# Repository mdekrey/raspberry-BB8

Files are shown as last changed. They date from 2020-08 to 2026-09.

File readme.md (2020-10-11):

# Raspberry-BB8

One developer's adventure into building a BB-8 replica, with help from his wife and friends.

## Equipment

I'm using:

* Raspberry Pi 3 model B

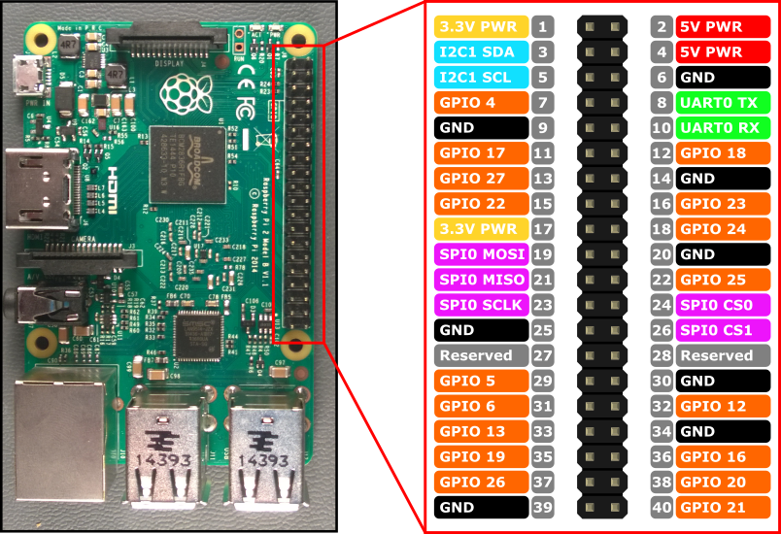
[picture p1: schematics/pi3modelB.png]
GPIO out for Raspberry Pi
    

* OSEPP Motor and Servo Shield v1.0

    OSEPP Motor and Servo Shield v1.0 Schematic

## Warnings and Pitfalls

- The Raspberry Pi 3 model B has a power management issue running the onboard wifi and bluetooth at the same time. Disable wifi if you're using the bluetooth controller, or use external dongles for either. When using wifi, the bluetooth controllers would intermittently not connect, etc.
- The OSEPP Motor and Servo Shield v1.0 Schematic had M3 and M4 reversed from what was printed on my board, and only really came with schematics for the underlying chips. See [my Programmer's Guide for the OSEPP Motor and Servo Shield](./programmers-guide-to-osepp-motor-shield.md).

## Building

1. Package the BB8 project in this repository using `dotnet`.

        dotnet publish -c Release -p:PublishSingleFile=false -p:PublishTrimmed=true -r linux-arm

    This is also saved in `publish.ps1`. With .NET 5 RC1, I found I needed turn off Single File publishing. It worked fine with .NET 5 Preview 7, however.

2. Copy the files from `\src\BB8\bin\Release\net5.0\linux-arm\publish` via to the Pi.

    * I [set up an SSH server on my Windows 10 machine within WSL.](https://superuser.com/a/1114162/45815)
    * I symlinked my publish folder to a folder in my WSL home to make it easy to find. (This really is unnecessary.)
    * I then used SCP to pull the file to my Raspberry Pi.

3. Run the project via `sudo`:

        sudo BB8

    `sudo` is necessary to use the hardware PWM features.

## Setup

Once you have the code built, you'll need to set up your configuration. By pairing a device

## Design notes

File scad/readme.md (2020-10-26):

# My BB-8 build

# Sources and info summary

## https://steemit.com/starwars/@mitchhunter/real-bb-8-and-you-can-have-one-too-part-1-of-my-adventure-in-building-full-scale-droid-from-star-wars

Detailed images, including 3d-printed parts, panel breakdowns, and lots of encouraging words.

## https://www.instructables.com/id/11-Scale-Replica-BB-8-Prop/

Images were helpful

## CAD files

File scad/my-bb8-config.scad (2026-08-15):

$fnBody = 360 / ($preview ? 5 : 2);
$fn = 360/ ($preview ? 10 : 5);
$fnDetail = $preview ? 15 : 60;

smallPrintBed = false;

millisPerInch = 25.4;
radius = 253; // rimstar.org has it at diameter of both 506 and 508 in different spots, but this is what I started at, so I'm keeping it for the moment.
wallThickness = 0.5 * millisPerInch;
camlockNutRadius = 2.6;
camlockNutThickness = wallThickness * 0.6;
camlockNutWallThickness = 1.6;
camlockNutMaxDepth = 10;
camlockNutGripSize = 1;
camlockBoltRadius = 2.5;
camlockBoltLength = 25;
fittedTolerance = 0.3;
pinRadius = camlockBoltRadius;
pinLength = camlockBoltLength;
adjacentCamlockOffsetStart = 7.5;
adjacentCamlockOffsetStep = 7.5;
adjacentCamlockOffsetMax = 20;
panelOverlapFactor = 0;
maxLip = 0;
ringLocksPerQuadrant = 6;

include <shared.scad>;

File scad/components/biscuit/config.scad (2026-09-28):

biscuitWidth = 8;
biscuitLength = 12;
biscuitThickness = 2.4;
biscuitRadius = 2;
biscuitSlotDepth = biscuitThickness + 1;

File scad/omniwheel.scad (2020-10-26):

radius = 120/2;
axleDiameter = 5;
axleLength = 25;
axleWheelBuffer = 0.1;
axleDiscBuffer = 0.3;
wheelCount = 5;
spokeWidth = 7;
spokeBuffer = 2;
tipBuffer = 10;
wheelBuffer = 3;
ribSize = 0.6;
ribSpacing = 3;
discThickness = 8;
boltRadius = 3.5/2;
boltHeadRadius = 5.5 / 2;
mainBoltRadius = 4.5/2;
hexTolerance = 0.1;

// Corresponds to Pololu Universal Aluminum Mounting Hub
// hubRadius = 9.5;

*preview();
*wheel();
*wheelHalf();
*rotate([180,0,0]) disc(true);
rotate([180,0,0]) disc(false);

function circleRadius(r, $fn) = r / cos(360 / 2 / $fn);

wheelRotation = 360 / wheelCount;
shift = radius * cos(wheelRotation / 2);

wheelHeight = 2 * radius * sin(wheelRotation / 2) - tipBuffer;

wheelMaxRadius = (radius - shift);

module preview() {
    for (i = [0:wheelCount]) {
        rotate([0,wheelRotation * i, 0])
        translate([shift,0,0])
        wheel();
    }

    rotate([90,0,0])
    disc(true);

    rotate([-90,0,0])
    disc(false);
}

module wheel() {
    spokeOffset = (spokeWidth + spokeBuffer) / 2;

    translate([0, 0, spokeOffset])
    wheelHalf();

    rotate([180, 0, 0])
    translate([0, 0, spokeOffset])
    wheelHalf();

    axle();
}

module wheelHalf() {
    spokeOffset = (spokeWidth + spokeBuffer) / 2;

    rotate_extrude(convexity=10,$fn=60)
    {
        intersection()
        {
            union() {
                for(y=[ceil(spokeOffset / ribSize / ribSpacing)*ribSize*ribSpacing-ribSize/3*ribSpacing:ribSize*ribSpacing:wheelHeight / 2]) {
                    for (m=[-1:2:2]) { // positive and negative
                        translate([cos(asin(y / radius)) * radius - shift - 0.1, y*m-spokeOffset])
                        rotate(asin(y / radius) + 45)
                        square([ribSize, ribSize], center=true);
                    }
                }
                intersection()
                {
                    translate([-shift,-spokeOffset]) circle(r=radius,$fn=60);
                    translate([shift,-spokeOffset]) circle(r=radius,$fn=60);
                }
            }

            union() {

                translate([0,(axleLength) / 2 - spokeOffset])
                    square([wheelMaxRadius,wheelHeight / 2 - axleLength / 2]);
                translate([axleDiameter / 2 + axleWheelBuffer,0])
                    square([wheelMaxRadius,wheelHeight / 2 - spokeOffset]);
            }
        }
    }
}

module axle() {
    actualAxleLength = max(axleLength, (spokeWidth + spokeBuffer) / 2 + 1);

    cylinder(r=axleDiameter / 2, h=actualAxleLength, center=true, $fn=60);
}

module disc(hexHole) {
    difference() {
        linear_extrude(height = discThickness / 2) {
            difference() {
                circle(r=radius - wheelMaxRadius);

                for (i = [0:wheelCount]) {
                    rotate(wheelRotation * i)
                    translate([shift + radius - wheelMaxRadius - wheelBuffer, 0])
                    circle(r = radius);
                }

                if (hexHole) circle(r=circleRadius(r=6, $fn=6) + hexTolerance, $fn=6);
                else circle(r=mainBoltRadius, $fn=60);

                *for (i = [0:6]) {
                    rotate(30+60*i)
                    translate([hubRadius, 0])
                    circle(r=boltRadius, $fn=60);
                }
            }

            for (i = [0:wheelCount]) {
                difference() {
                    rotate(wheelRotation * i)
                    translate([radius/2, -spokeWidth / 2])
                    square([radius/2 - wheelMaxRadius + spokeWidth / 2 + axleDiameter / 2, spokeWidth]);


                    rotate(wheelRotation * i)
                    translate([radius - wheelMaxRadius * 2 - max(0, boltHeadRadius - spokeWidth / 2), 0])
                    circle(r=boltRadius, $fn=60);
                }
            }

        }

        for (i = [0:wheelCount]) {
            rotate([90, 0, wheelRotation * i])
            translate([radius - wheelMaxRadius, 0, 0])
            cylinder(r=axleDiameter / 2 + axleDiscBuffer, h=spokeWidth + 1, center=true, $fn=60);
        }

    }
}

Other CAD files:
scad/cap-cover.scad
scad/camlock-test.scad
scad/components/biscuit/biscuit.scad
scad/components/biscuit/slot.scad
scad/deprecated/camlock-test.scad
scad/deprecated/hex-bolt-adapter.scad
scad/deprecated/my-bb-8-tiny.scad
scad/my-bb8-glue-bracket.scad
scad/my-bb8-head.scad
scad/my-bb8-overview.scad
scad/my-bb8-panel-1.scad
scad/my-bb8-panel-2.scad
scad/my-bb8-panel-3.scad
scad/my-bb8-panel-4.scad
scad/my-bb8-panel-5.scad
scad/my-bb8-panel-6.scad
scad/my-bb8-ring-quarter.scad
scad/my-bb8-triangle-third.scad
scad/my-bb8-triangle.scad
scad/pi-bracket.scad
scad/shared.scad
scad/test-biscuit.scad

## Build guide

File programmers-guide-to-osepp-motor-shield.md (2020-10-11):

# A Programmer's Guide to OSEPP Motor & Servo Sheild V1.0

The OSEPP Motor & Servo Sheild V1.0 is designed for Arduino users and electrical
engineers; I am neither of those things, but I'm going through decyphering what
little information I can find on the internet and compiling it into a single document.

Here's my board for reference, in case it changes in the future. Sorry for the
extra wires. I really don't want to lose my place!

-- TODO - add image --

[Here's the actual schematic.](./schematics/OSEPP_motor_shield_v1-0.svg)

## Terms

If you're not used to digital programming, here's some terms with which you may
not be familiar. I'm not going to straight up define them; I'd be wrong to some
degree. Instead, I'm going to provide tiny anecdotes that will hopefully provide
the information you need.

* Phase Width Modulation (or PWM) - Imagine a volume knob, where you can dial it
  from 0-10 (definitely not 11). If you set the knob to 5, the sound will be
  roughly half the volume constantly. This is known as "amplitude modulation".
  Unfortunately, given friction, resistances in voltage, etc., motors and servos
  do not work this way - giving a motor half the voltage it needs (or amps,
  etc.) wouldn't give half the speed. Instead, with a "5 of 10", we give full
  power for half the time, and half the power for half the time.
* Motor
* Servo
* Pin
* Serial
* Data
* Latch
* Clock
* Digital
* Analogue
* Voltage
* Ground

## Chips

This shield essentially wires together these two chips:

  * a 74x595 chip (specifically the 74HCT595D chip) https://www.nxp.com/documents/data_sheet/74HC_HCT595.pdf
    - This converts a serial data stream into 7 outputs and a carry. In this way, a total of 3 pins can be used to control several outputs. However, this shield
        doesn't provide access to the carry, instead using all 8 outputs to drive the 4 motors.
  * two L293D chips http://www.ti.com/lit/ds/symlink/l293.pdf
    - Each chip drives two motors by amplifying the PWM stream with an enable bit up to the input voltage for the motors.

## Pins

### Digital I/O

The digital I/O pins are along the top of the board, starting in the upper right
at 0, moving to the left for increasing numbers.

0. Unused (Schema is blank)
1. Unused (Schema is blank)
2. Unused (Schema is blank)
3. Phase Width Modulation of Motor 2 (Schema is PWM2B)
4. Serial Clock Pin (Schema is DIR_CLK)
5. Phase Width Modulation of Motor 4 (Schema is PWM0B)
6. Phase Width Modulation of Motor 3 (Schema is PWM0A)
7. Ground, essentially. This is the "output enable" toggle, but negated due to the original chip. (TBD, how do you say this out loud?) (Schema is labelled DIR_EN)
8. Serial Data Pin (Schema is DIR_SER)
9. Phase Width Modulation of Servo 2 (TODO - verify) (Schema is PWM1A)
10. Phase Width Modulation of Servo 1 (TODO - verify) (Schema is PWM1B)
11. Phase Width Modulation of Motor 1 (Schema is PWM2A)
12. Serial Latch (Schema is DIR_LATCH)
13. Unused (Schema is blank)
14. (labelled `gnd`) Ground
15. (labelled `ARef`) Unused

Note here that the board is labelled M3 at the bottom, and the schematic said
that 5 went to M3 and 6 went to M4. I chose to keep what was printed on my board
rather than what the schematic said.

#### Serial Data

Serial data repeats 8 bits to enable/disable the motors.

0. M4 forward (hex 0x01)
1. M2 forward (hex 0x02)
2. M1 forward (hex 0x04)
3. M1 backward (hex 0x08)
4. M2 backward (hex 0x10)
5. M3 forward (hex 0x20)
6. M4 backward (hex 0x40)
7. M3 backward (hex 0x80)

Note here that the board is labelled M3 at the bottom, and the schematic said
that 5/7 went to M4. I chose to keep what was printed on my board rather than
what the schematic said.

### Analog In

Pins supported as a pass-through to the Arduino. Unused.

### Other Pins

From right-to-left, separate block of 6 from the "analog in" pins.

* `VIn`: Default low-voltage input for the board (see Jumpers)
* `Gnd`: Ground
* (unlabelled): Ground
* `5v`: 5 volts to use as reference for comparing serial data
* `3v`: Unused, but intended as a pass-through of 3 volts to another shield
* `RST`: Connects to ground when Reset is pushed. (Not applicable in this guide)

### Jumpers

* JP1:
    * When 1/2 are connected, uses VIn for voltage to the servos.
    * When 2/3 are connected, uses SERVO VSrc terminal (bottom left of board) for voltage to the servos.
* JP2:
    * When 1/2 are connected, uses VIn for voltage to the motors.
    * When 2/3 are connected, uses MOTOR VSrc for voltage to the motors.

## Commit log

2016-08-17 Add software PWM test
2016-08-17 Improve PWM performance
2016-08-17 Improve PwmThread use
2016-08-19 Motors are spinning!
2020-08-01 Extract shared file
    [my-bb-8-tiny.scad, my-bb-8.scad, shared.scad]
2020-08-01 Camlock nut and bolts
    [my-bb-8-tiny.scad, my-bb-8.scad, shared.scad]
2020-08-02 Improve camlocks and build tester
    [camlock-test.scad, my-bb-8-tiny.scad, my-bb-8.scad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]
2020-08-02 Improve camlocks, add visible bolt holes
    [camlock-test.scad, my-bb-8-tiny.scad, my-bb-8.scad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]
2020-08-03 Add panel ring - it's close
    The panel ring here doesn't have the rotate lock slot in the right spot
    due to the panel overlap.
    [my-bb-8-tiny.scad, shared.scad]
2020-08-03 WIP panel ring
    [my-bb-8-tiny.scad, shared.scad]
2020-08-04 Second ring attempt
    [my-bb-8-tiny.scad, my-bb-8.scad, shared.scad]
2020-08-06 Correct bolt radius treatment
    [my-bb-8-tiny.scad, my-bb-8.scad, shared.scad]
2020-08-07 Add additional frame adjacent holes for stability
    [my-bb-8-tiny.scad, my-bb-8.scad, shared.scad]
2020-08-07 Use native PWM
2020-08-08 Add configuration (and overrides) for pin uses
2020-08-09 Refactor motors to domain logic and adapter
2020-08-09 Add dead zone for power
2020-08-10 Motor tools
    [hex-bolt-adapter.scad, omniwheel.scad]
2020-08-10 Omniwheel tweaks
    [omniwheel.scad]
2020-08-10 WIP tool panels
    [my-bb-8-tiny.scad, my-bb-8.scad, shared.scad]
2020-08-10 Add ring designs
    [my-bb-8-tiny.scad, my-bb-8.scad, shared.scad]
2020-08-12 Design panels
    [my-bb-8-tiny.scad, my-bb-8.scad, shared.scad]
2020-08-15 Minor tweaks for outer ring
    [my-bb-8.scad, shared.scad]
2020-08-17 Add depth to the ring end holes
    [shared.scad]
2020-08-17 Add panel glue brackets
    [my-bb-8.scad, shared.scad]
2020-08-18 Refactor gamepad and map other motors
2020-08-18 Refactor gamepad for button mappings
2020-08-19 Correct schematic and add all motors
2020-08-19 Improve motor configuration
2020-08-23 Build the robot
    [my-bb-8.scad, pi-bracket.scad, shared.scad]
2020-08-27 Build complete bracket with top-mounted circuits
    [pi-bracket.scad]
2020-08-27 Refactor battery bracket
    [pi-bracket.scad]
2020-08-30 Move circuitry bracket to sides
    [pi-bracket.scad]
2020-09-05 Improve panel designs via programmable SVGs
    [my-bb-8.scad, shared.scad]
2020-10-12 Minor refactorings to correct motor function
2020-10-12 Add powershell scripts for faster iteration
2020-10-15 Correct power pin configuration
2020-10-25 Improve mapping of motors
2020-10-26 Many updates for final v1 build
    [cap-cover.scad, hex-bolt-adapter.scad, my-bb-8-tiny.scad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]
2020-10-26 Move folder
    [camlock-test.scad, cap-cover.scad, hex-bolt-adapter.scad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]
2020-10-26 Mark another deprecated file
    [camlock-test.scad]
2020-10-26 Refactor large scad into individual files
    [my-bb-8.scad, my-bb8-config.scad, my-bb8-glue-bracket.scad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]
2020-10-26 Remove unused modules
    [shared.scad]
2020-10-26 Refactor panels for more efficient rendering
    [shared.scad]
2020-10-26 Remove dead code
    [shared.scad]
2020-12-06 Begin rebuilding for smaller battery
    [pi-bracket.scad]
2020-12-06 Design new lower bracket
    [pi-bracket.scad]
2020-12-06 Slight refactoring
    [pi-bracket.scad]
2020-12-11 Final caddy for small battery
    [pi-bracket.scad]
2026-08-15 Begin improving design
    [my-bb8-config.scad, my-bb8-triangle.scad, shared.scad]
2026-08-15 Simplify clipping for tolerance
    [shared.scad]
2026-08-15 Use simple values during debugging
    [my-bb8-config.scad]
2026-08-15 Improve rotate lock slots
    [shared.scad]
2026-08-15 Improve control over panel-x
    [shared.scad]
2026-08-15 Allow preview of panel with ring part
    [my-bb8-panel-1.scad, shared.scad]
2026-08-15 Add support for panel 0 being blank
    [shared.scad]
2026-08-15 Correct design X-exclusion
    [shared.scad]
2026-08-15 Add small-printbed flag
    [my-bb8-config.scad, shared.scad]
2026-08-15 Note correct radius
    [my-bb8-config.scad]
2026-08-15 Add initial head part
    [my-bb8-config.scad, my-bb8-overview.scad, shared.scad]
2026-08-15 Add head detail file
    [my-bb8-head.scad, shared.scad]
2026-08-15 Add some detail to the head
    [shared.scad]
2026-08-15 Standardize visible bolt holes in t-frame
    [shared.scad]
2026-08-15 Simplify t-frame triangle
    [shared.scad]
2026-09-06 Add biscuit connector test
    [my-bb8-config.scad, shared.scad, test-biscuit.scad]
2026-09-06 Ignore STL files
2026-09-06 Add reamining pieces for test
    [test-biscuit.scad]
2026-09-06 Decrease test size
    [my-bb8-config.scad, test-biscuit.scad]
2026-09-16 Improve test biscuit
    [shared.scad, test-biscuit.scad]
2026-09-18 Move to components for better mergeability
    [biscuit.scad, config.scad, my-bb8-config.scad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]
2026-09-28 Adjustments for second test biscuit print
    [config.scad, test-biscuit.scad]
2026-09-28 Final biscuit modifications
    [test-biscuit.scad]
